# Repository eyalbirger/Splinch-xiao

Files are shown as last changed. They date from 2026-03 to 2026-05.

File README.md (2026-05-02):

# Splinch xiao
this is a 60 keys split ortho col staggered wireless keyboard that uses the 
xiao nrf52840 as its micro controller and zmk as firmwere.

i decided to build this because my current 60% razer gaming keeb, which has really bad software, hurts my wrist, ugly and sounds really annoying.
i got the idea to build this when i saw the ferris sweep on youtube and it looked supppppper cool.

BOM:
| name | quantity | value | lcsc # | price | source | pic |
|:----:|:---:|:-----:|:---:|:-----:|:---:|:---:|
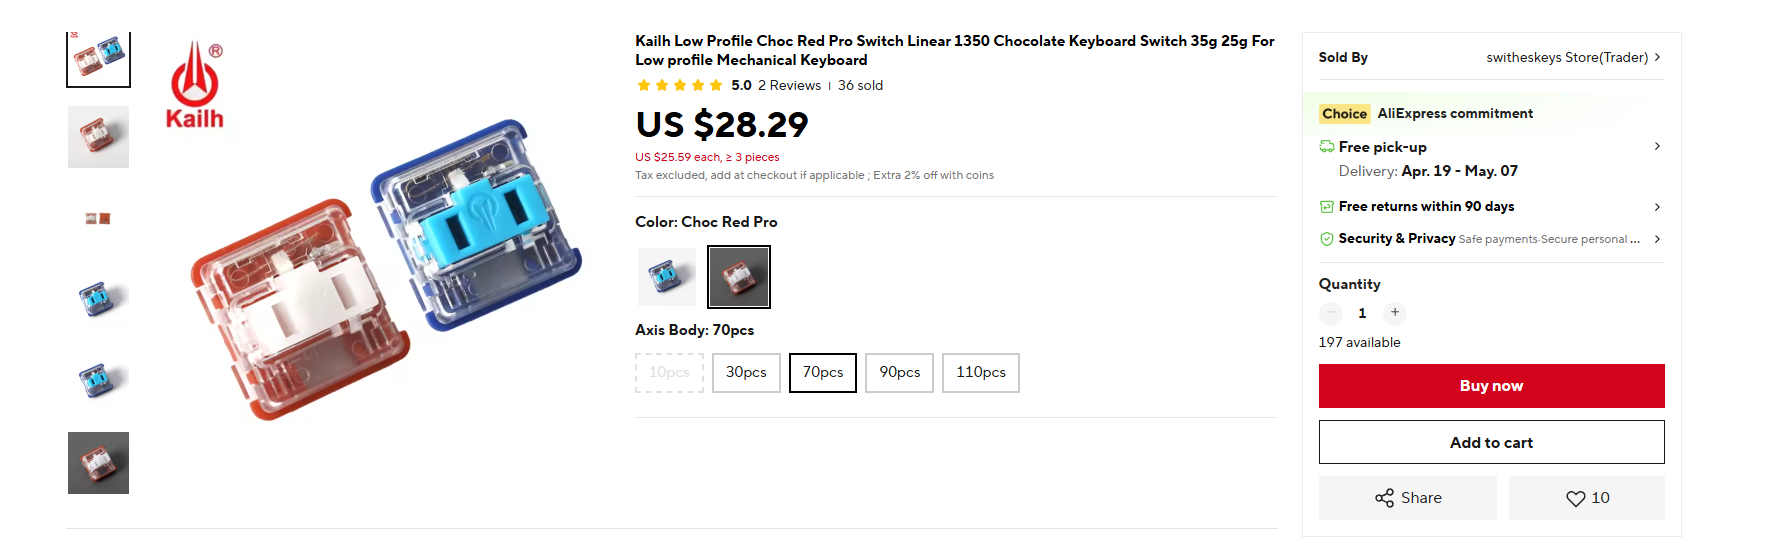
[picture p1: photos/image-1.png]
| choc switches | 62 | - | - | 30$ | https://he.aliexpress.com/item/1005010420712566.html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 |  |
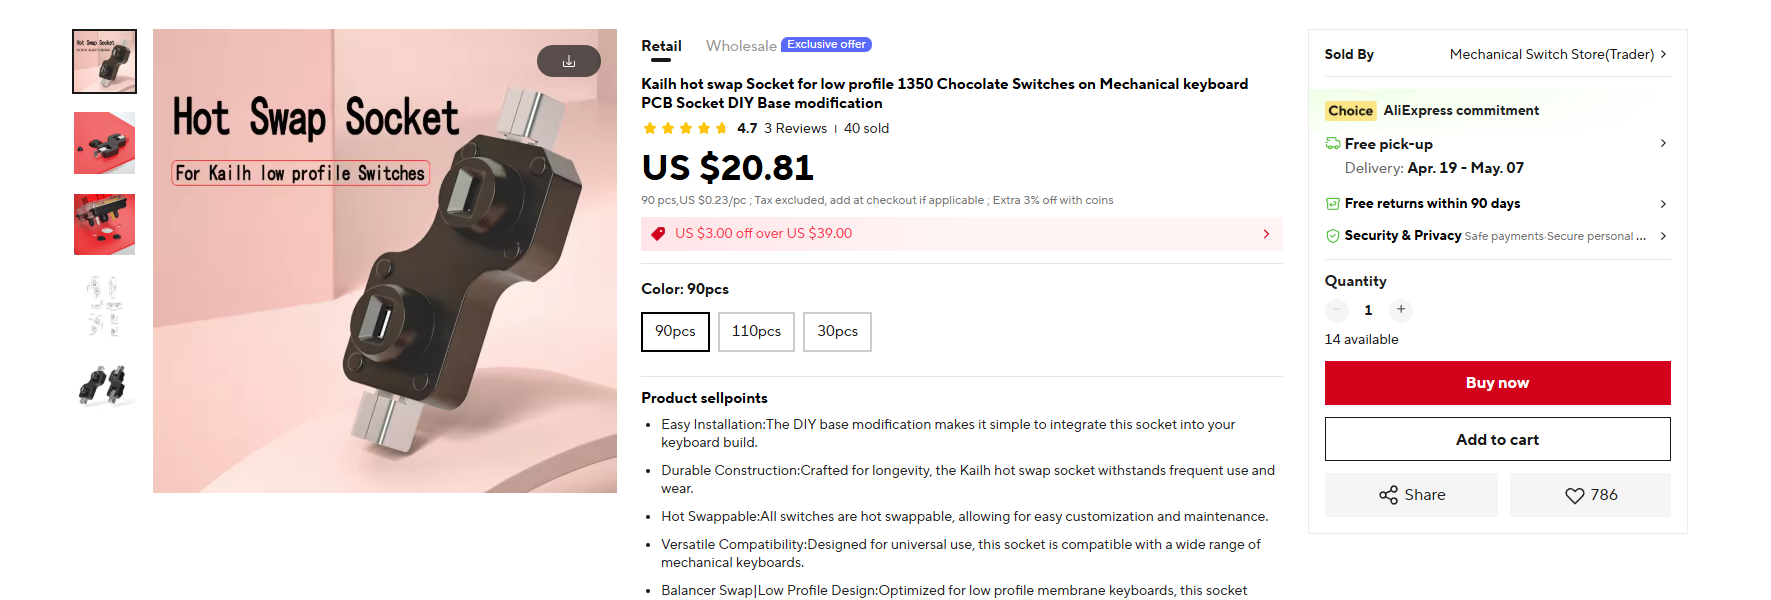
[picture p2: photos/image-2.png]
| choc hot swap socket | 62 | - | - | 20$ | https://he.aliexpress.com/item/33023283633.html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 |  |
| diodes | 62 | 1N4148W (SOD-123) | C2128 |
| resistor | 2 | 0805, 2M | C106170 | 
| resistor | 2 | 0805, 806k | C63494 |
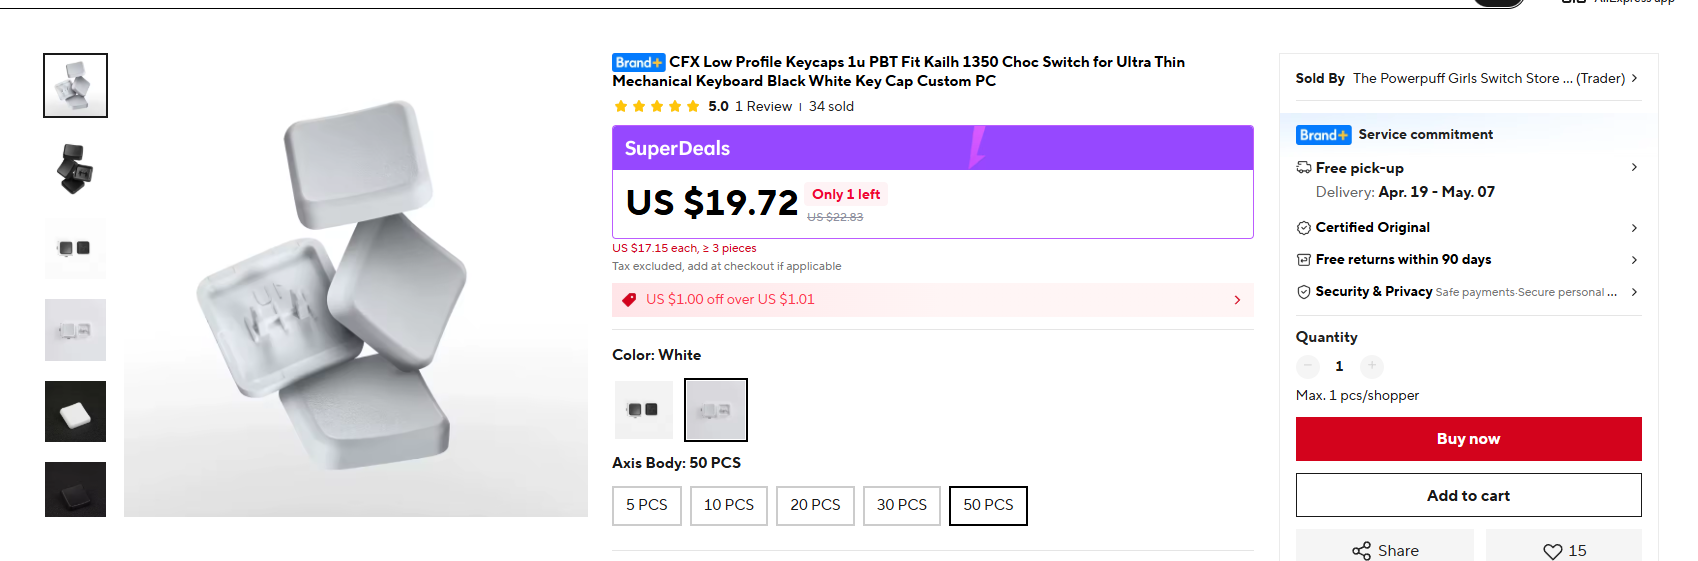
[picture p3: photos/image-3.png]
| keycaps | 62 | - | - | 27$ | https://he.aliexpress.com/item/1005010385514024.html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 |  |
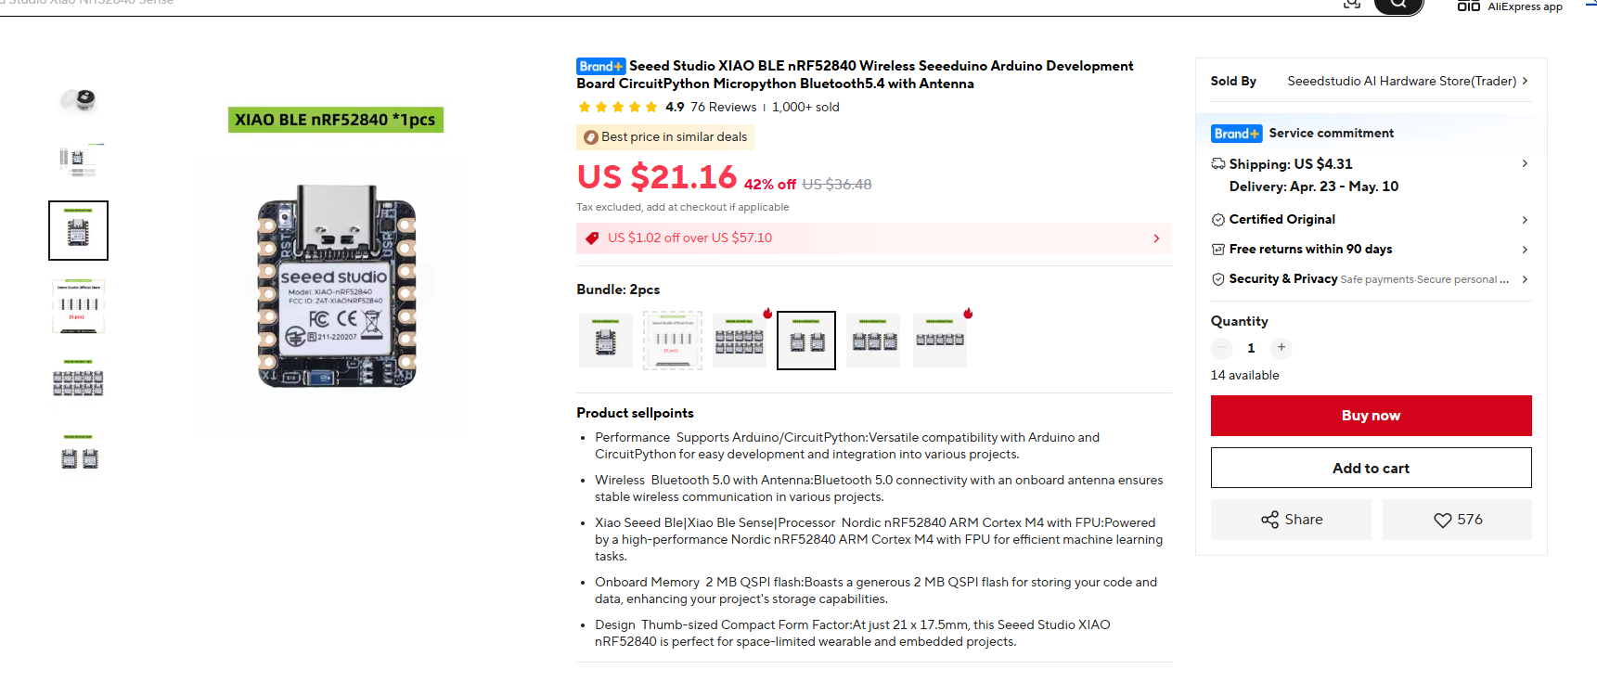
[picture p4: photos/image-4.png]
| nrf52 xiao | 2 | - | - | 40$ | https://he.aliexpress.com/item/1005006988954136.html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 |  |
| switch | 2 | MSK12C02 | - |
| screws | 8 | m2 | - |
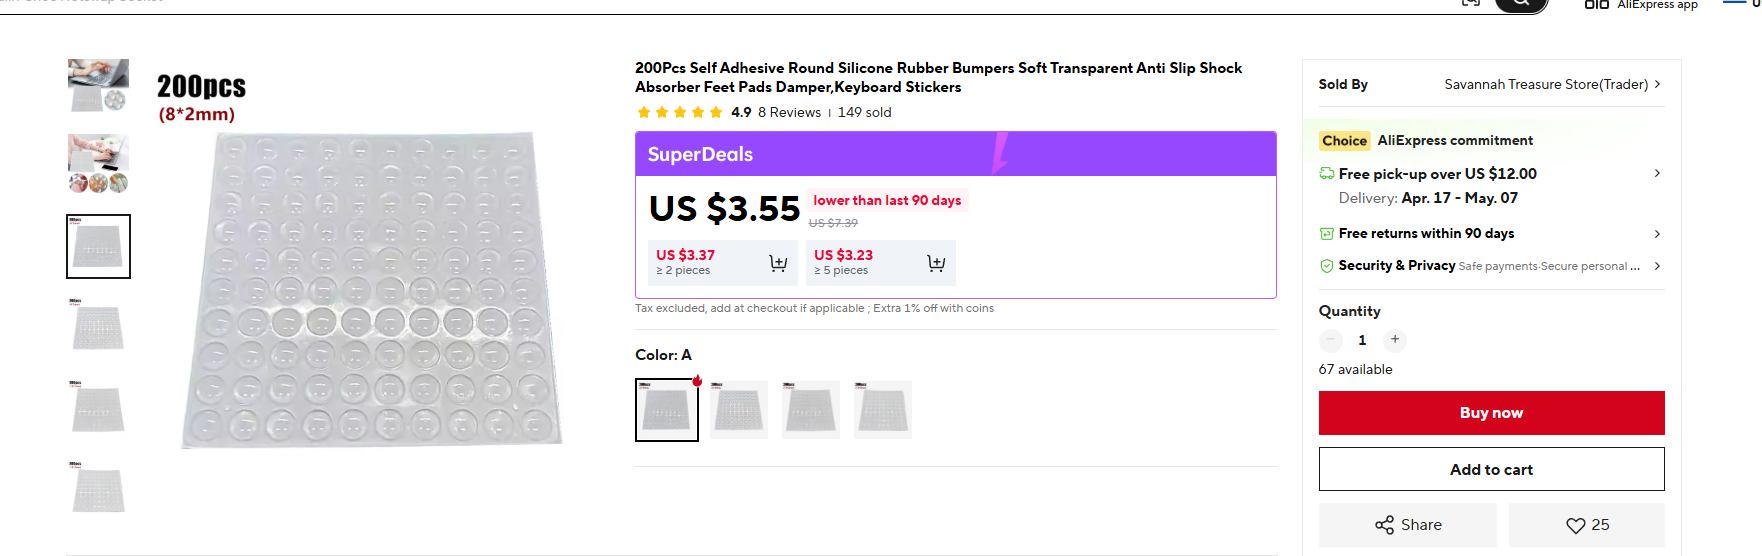
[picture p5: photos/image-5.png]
| silicone feet | some | - | - | 7$ | https://he.aliexpress.com/item/1005010241201821.html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 |  |
| nice nano | 1 | - | - | - | - | - |
| TOTAL | - | - | - | 124$ | - | - |

in order to complete that you also need the pcb. you can choose to use the pcba or assamble it yourself. i reccomend to use the pcba with the ressistors and the doides, and hand soldering the others.
this is the pcb:
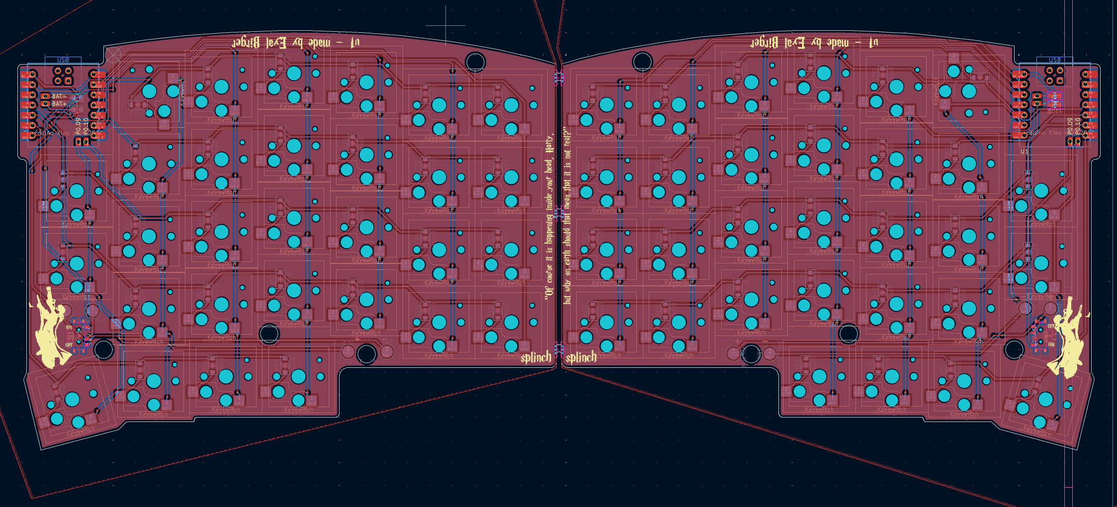
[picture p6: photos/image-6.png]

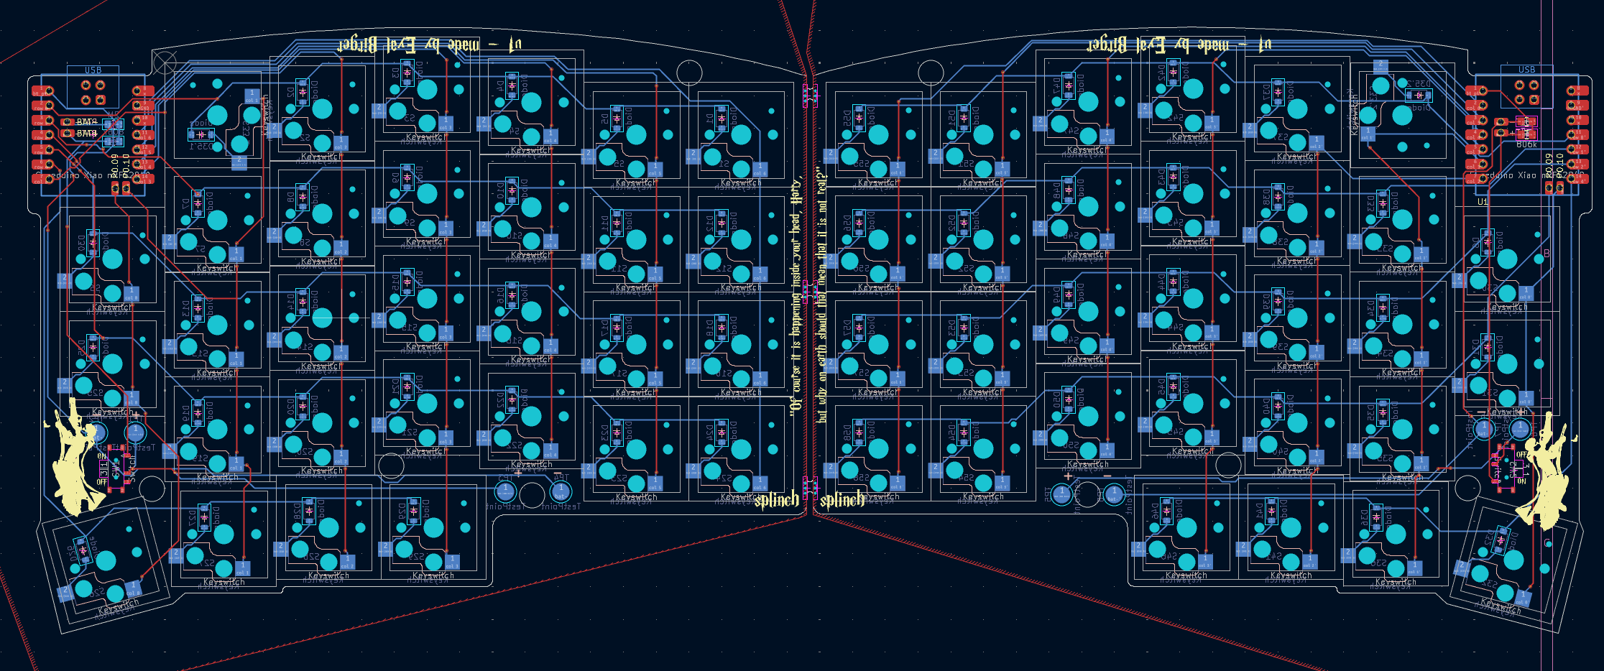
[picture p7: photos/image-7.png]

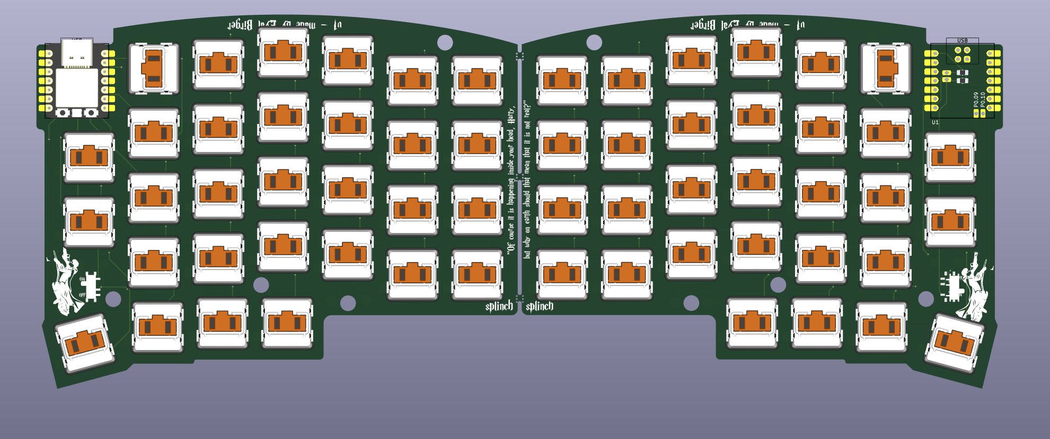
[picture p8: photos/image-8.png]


this is the case:
you need **8 m2 standoffs**, you can glue them with superglue into the standoff holes.
you also need **8 m2 screws** to screw the pcb to the case.
you can put a **6mm (max) thick battery**.
you need to mirror the case for the left part.
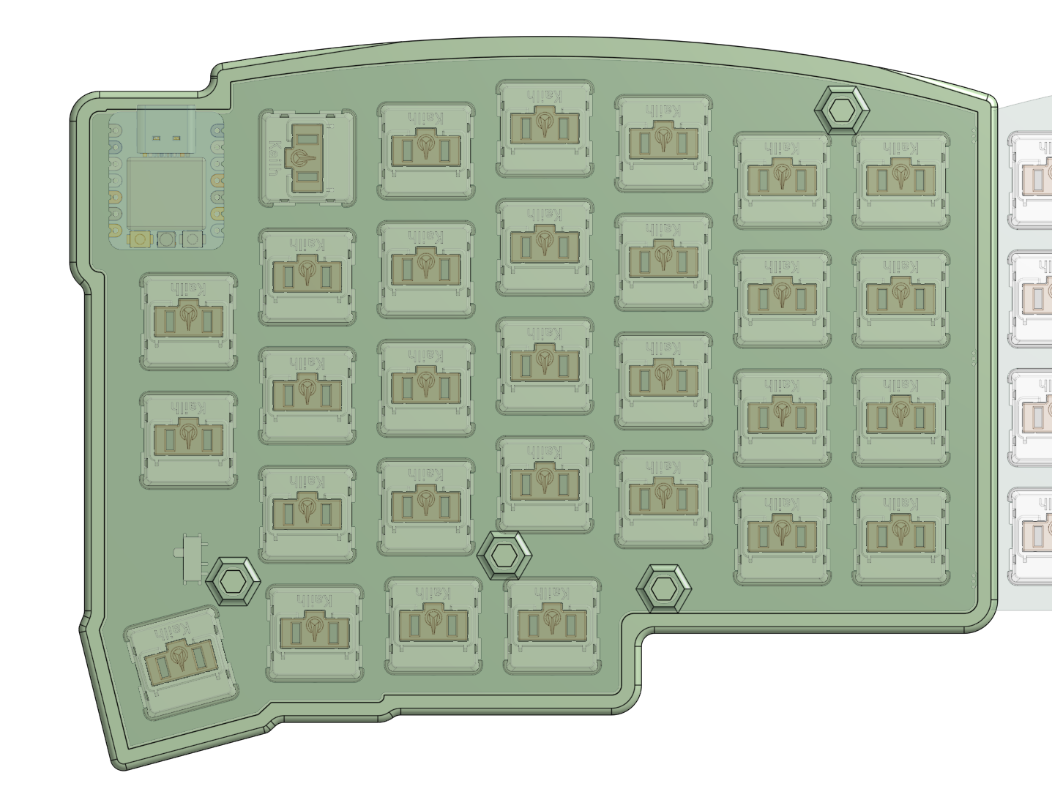
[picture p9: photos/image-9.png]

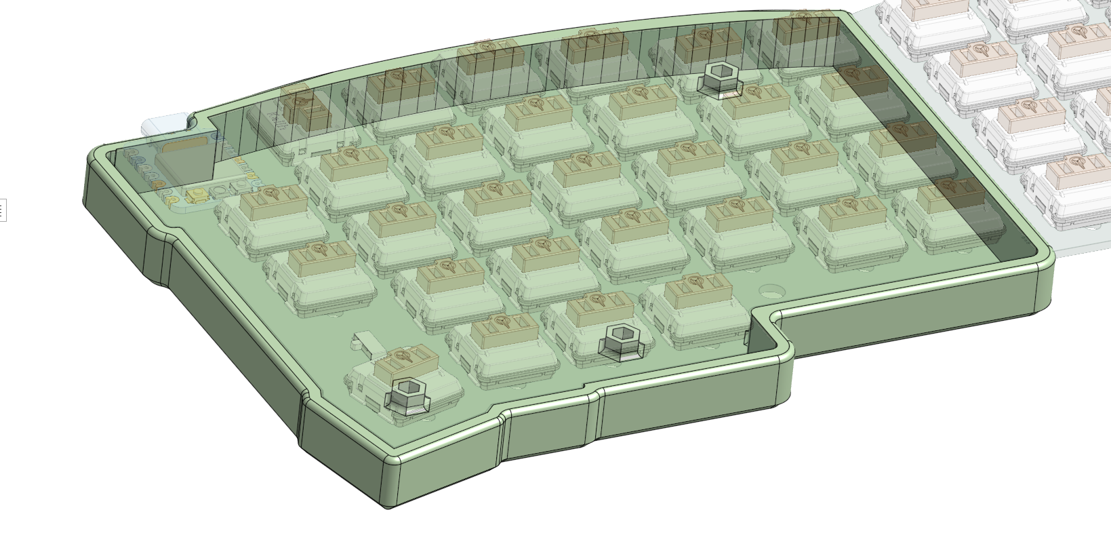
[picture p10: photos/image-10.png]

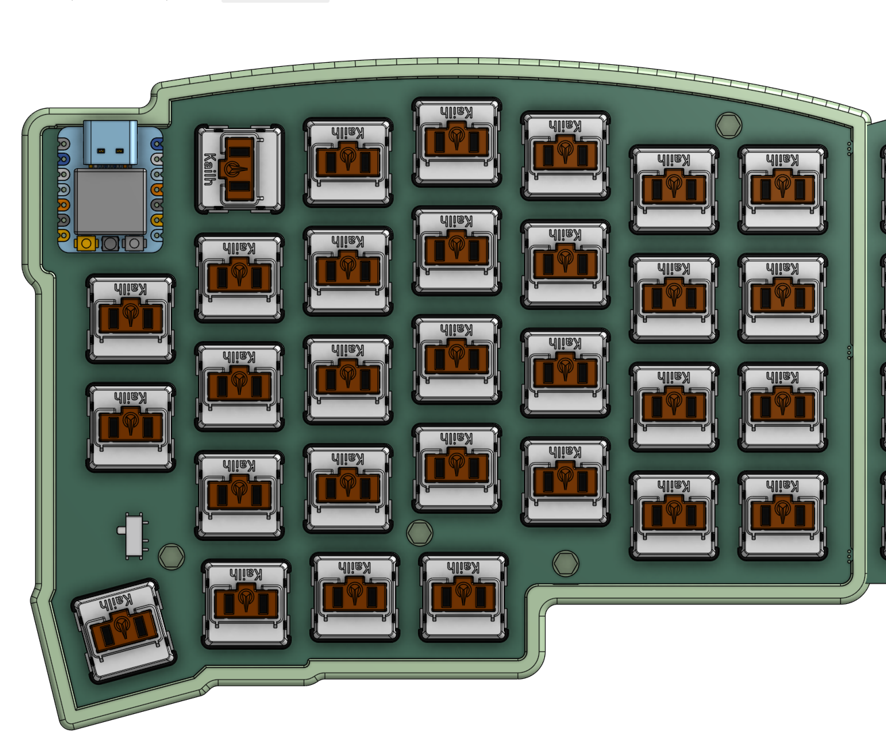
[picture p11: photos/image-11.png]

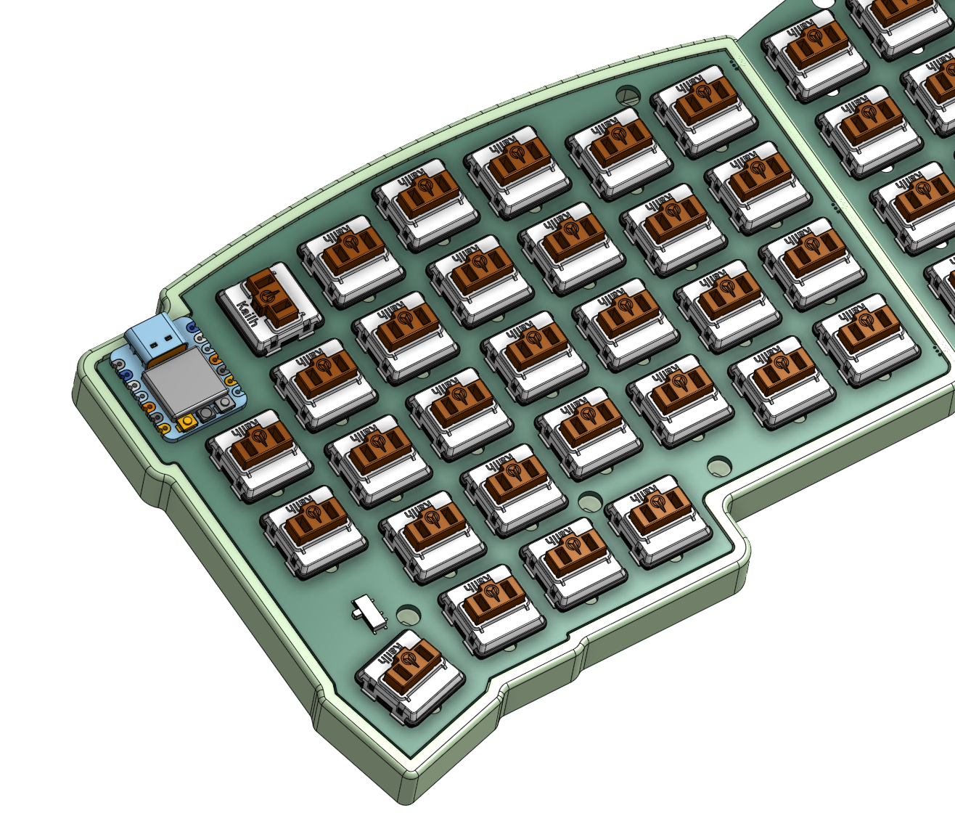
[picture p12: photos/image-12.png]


firmware: https://github.com/eyalbirger/zmk-config-splinch.git
i still need to complete and test the firmware (i have like one build error), but it will probably be completed in a few days (i have a war to deal with, so you know...).

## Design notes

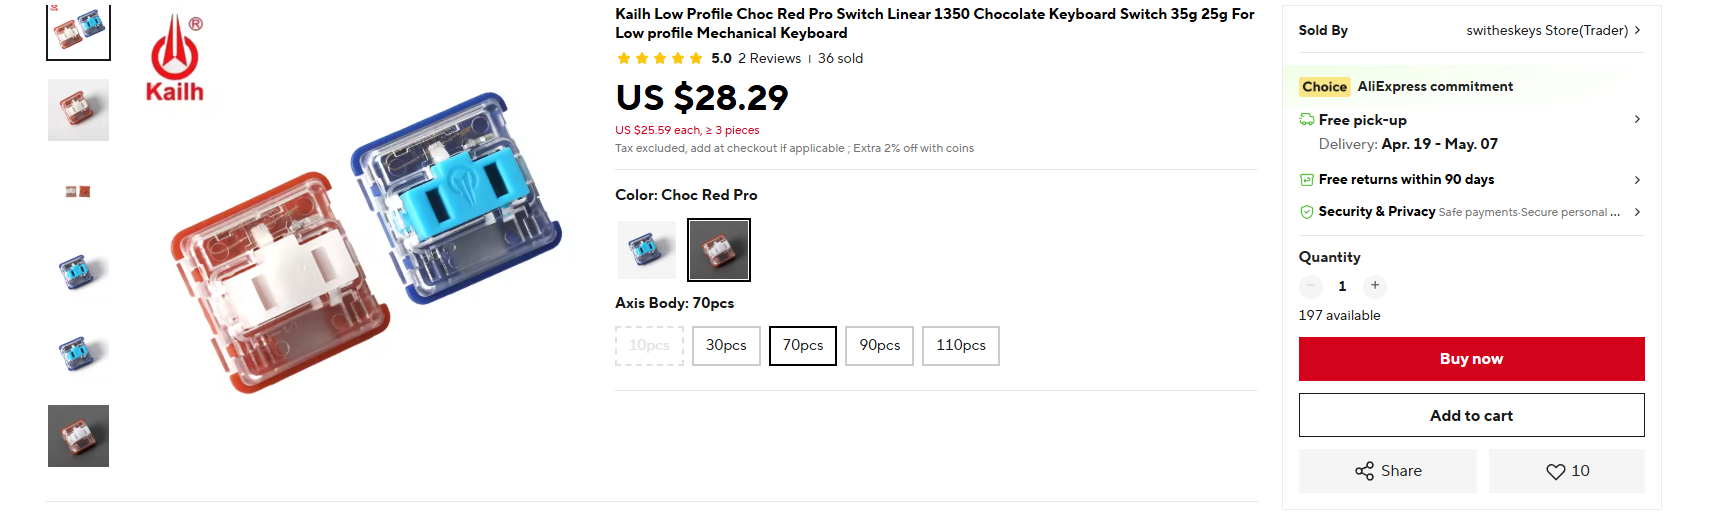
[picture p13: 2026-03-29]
photos/image.png

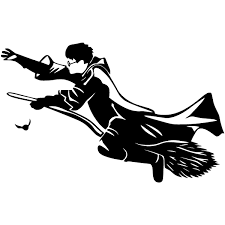
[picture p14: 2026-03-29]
Splinch xiao/photos/images.png

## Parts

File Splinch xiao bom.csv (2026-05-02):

Name | Quantity | Value | LCSC # | Price | Source
Choc switches | 58 | - | - | 30$ | https://he.aliexpress.com/item/1005010420712566.html
Choc hot swap socket | 58 | - | - | 20$ | https://he.aliexpress.com/item/33023283633.html
Diodes | 58 | 1N4148W (SOD-123) | C2128
Resistor | 2 | 0805 2M | C106170
Resistor | 2 | 0805 806k | C63494
Keycaps | 58 | - | - | 27$ | https://he.aliexpress.com/item/1005010385514024.html
NRF52 XIAO | 2 | - | - | 40$ | https://he.aliexpress.com/item/1005006988954136.html
Switch | 2 | MSK12C02 | -
Screws | 8 | M2 | -
Silicone feet | some | - | - | 7$ | https://he.aliexpress.com/item/1005010241201821.html
Nice Nano | 1 | - | -
TOTAL |  |  |  | 124$

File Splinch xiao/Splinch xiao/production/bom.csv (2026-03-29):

Designator | Footprint | Quantity | Value | LCSC Part #
D1, D10, D11, D12, D13, D14, D15, D16, D17, D18, D19, D2, D20, D21, D22, D23, D24, D25, D26, D27, D28, D29, D3, D30, D31, D32, D33, D34, D35, D35'1, D35'2, D36, D37, D38, D39, D4, D40, D41, D42, D43, D44, D45, D46, D47, D48, D49, D5, D50, D51, D52, D53, D54, D55, D56, D57, D58, D6, D7, D8, D9 | Diode_SOD-123 | 60 | Diode
R1, R3 | 0805 | 2 | 806k
R2, R4 | 0805 | 2 | 2M
S1, S10, S11, S12, S13, S14, S15, S16, S17, S18, S19, S2, S20, S21, S22, S23, S24, S25, S26, S27, S28, S29, S3, S30, S31, S32, S33, S33'1, S33'2, S34, S35, S36, S37, S38, S39, S4, S40, S41, S42, S43, S44, S45, S46, S47, S48, S49, S5, S50, S51, S52, S53, S54, S55, S56, S57, S58, S6, S7, S8, S9 | Kailh_socket_PG1350 | 60 | Keyswitch
SW1, SW2 | Switch_MSK12C02 | 2 | Switch
TP1, TP2, TP3, TP4, TP5, TP6, TP7, TP8 | TestPoint_Pad_D3.0mm | 8 | TestPoint

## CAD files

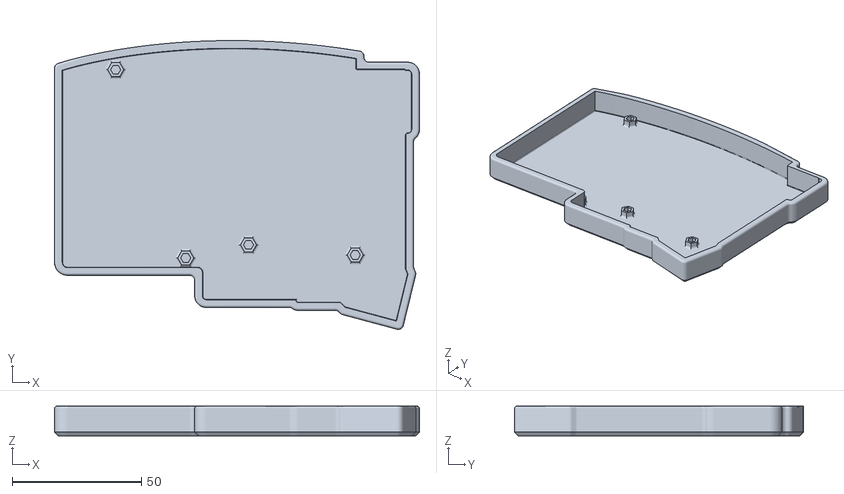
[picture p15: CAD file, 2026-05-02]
CAD/case left.stl
141.4 x 111.9 x 11.6

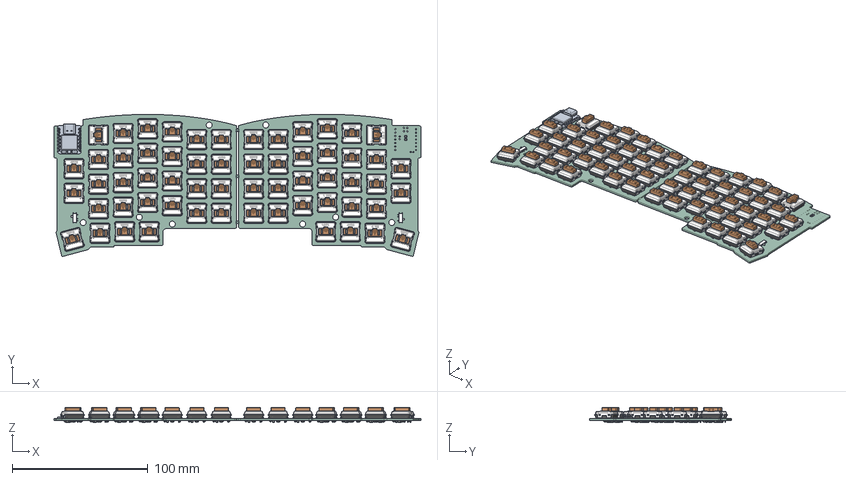
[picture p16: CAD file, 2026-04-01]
Splinch xiao/Splinch xiao/for cad/Splinch xiao.step
270.4 x 104.8 x 11.0 mm
Choc_V1 x 58
Splinch xiao 1.17.1
Switch_MSK12C02 x 2
R_0805_2012Metric x 4
Diode_SOD-123 x 58
Splinch xiao_PCB

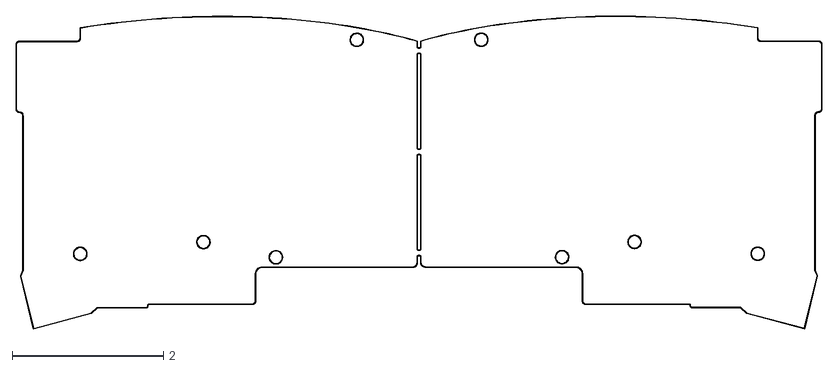
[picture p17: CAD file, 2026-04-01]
Splinch xiao/Splinch xiao/Splinch xiao-Edge_Cuts.dxf
10.6 x 4.13

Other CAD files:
CAD/case right stl.stl
CAD/case right step.step

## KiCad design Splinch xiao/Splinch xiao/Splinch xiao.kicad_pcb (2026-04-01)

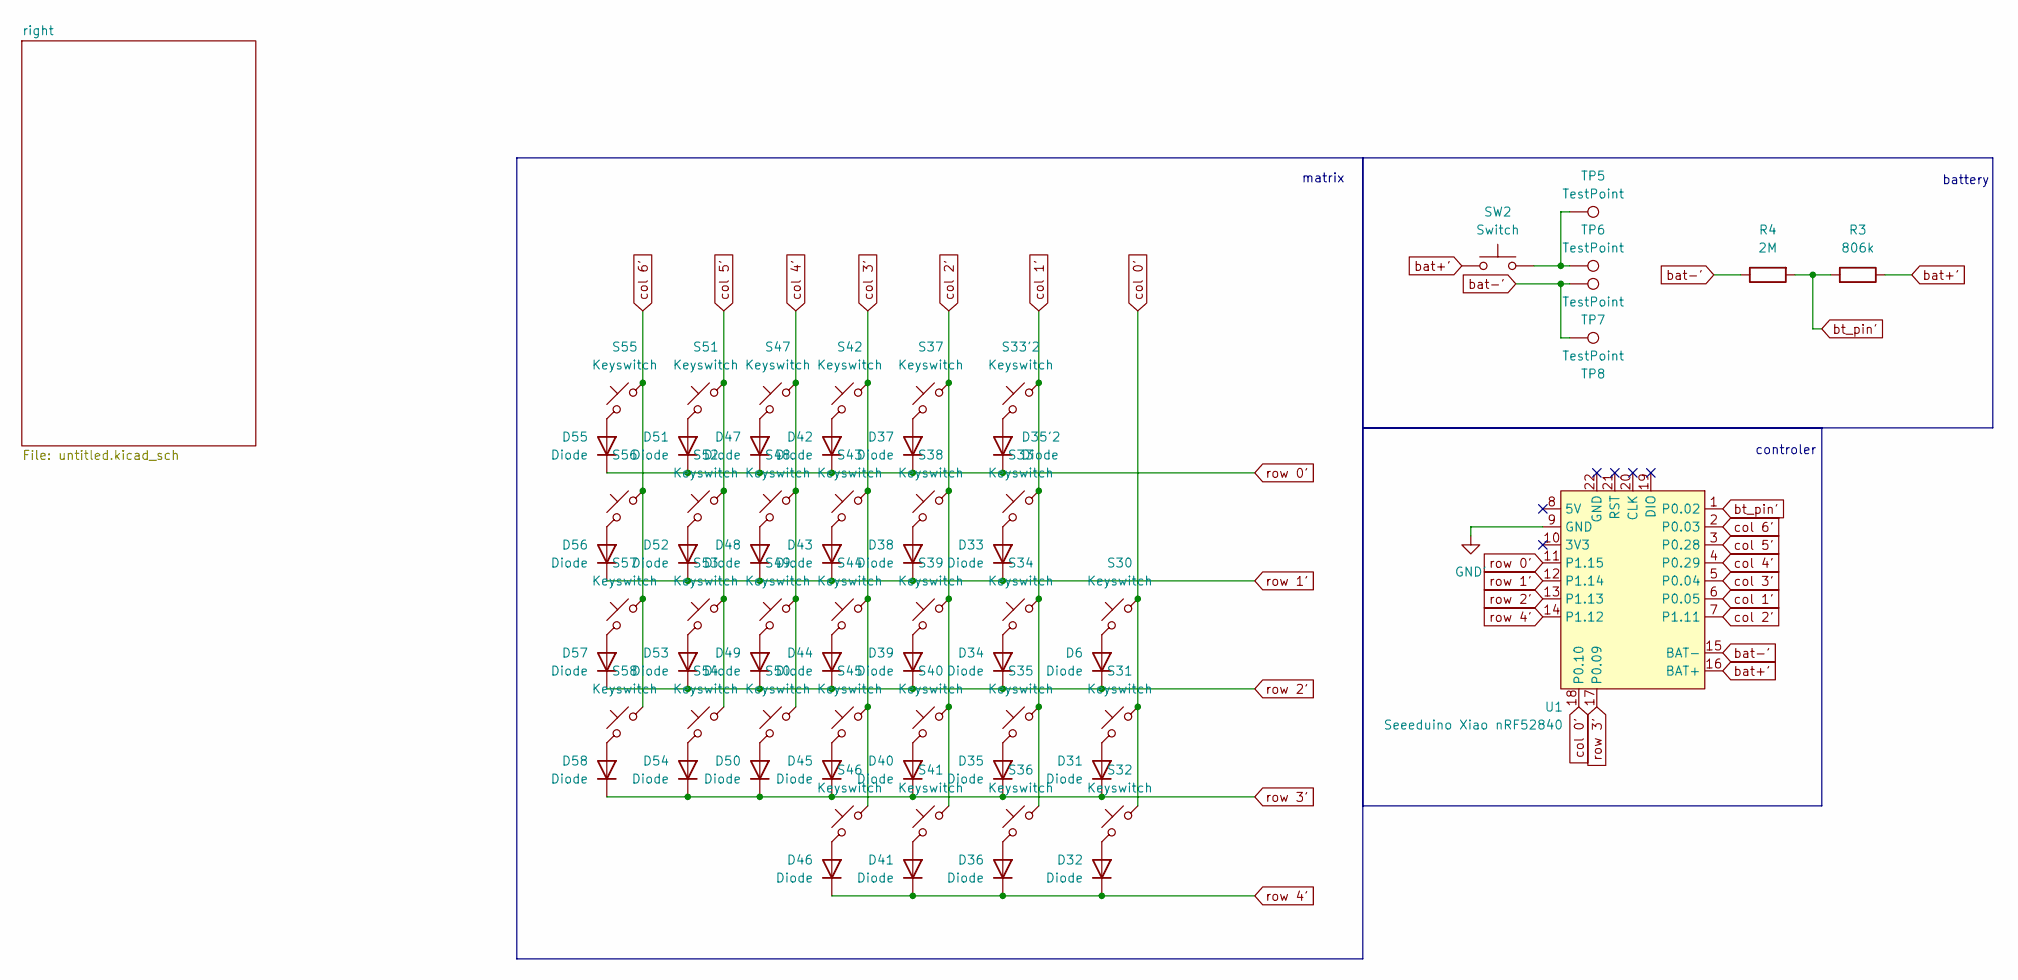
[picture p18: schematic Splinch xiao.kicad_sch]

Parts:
D6, D31, D32, D33, D34, D35, D35'2, D36, D37, D38, D39, D40, D41, D42, D43, D44, D45, D46, D47, D48, D49, D50, D51, D52, D53, D54, D55, D56, D57, D58: Diode; Diode_SOD-123; LCSC C2128
R3: 806k; R_0805_2012Metric_Pad1.20x1.40mm_HandSolder; LCSC C121025
R4: 2M; R_0805_2012Metric_Pad1.20x1.40mm_HandSolder; LCSC C106170
S30, S31, S32, S33, S33'2, S34, S35, S36, S37, S38, S39, S40, S41, S42, S43, S44, S45, S46, S47, S48, S49, S50, S51, S52, S53, S54, S55, S56, S57, S58: Keyswitch; Kailh_socket_PG1350
SW2: Switch; Switch_MSK12C02
TP5, TP6, TP7, TP8: TestPoint; TestPoint_Pad_D3.0mm
U1: Seeeduino Xiao nRF52840; Xiao_nRF52840_ACH

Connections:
GND': U1.9 (GND)
unnamed: D6.2 (A), S30.2
unnamed: D31.2 (A), S31.2
unnamed: D32.2 (A), S32.2
unnamed: D33.2 (A), S33.2
unnamed: D34.2 (A), S34.2
unnamed: D35'2.2 (A), S33'2.2
unnamed: D35.2 (A), S35.2
unnamed: D36.2 (A), S36.2
unnamed: D37.2 (A), S37.2
unnamed: D38.2 (A), S38.2
unnamed: D39.2 (A), S39.2
unnamed: D40.2 (A), S40.2
unnamed: D41.2 (A), S41.2
unnamed: D42.2 (A), S42.2
unnamed: D43.2 (A), S43.2
unnamed: D44.2 (A), S44.2
unnamed: D45.2 (A), S45.2
unnamed: D46.2 (A), S46.2
unnamed: D47.2 (A), S47.2
unnamed: D48.2 (A), S48.2
unnamed: D49.2 (A), S49.2
unnamed: D50.2 (A), S50.2
unnamed: D51.2 (A), S51.2
unnamed: D52.2 (A), S52.2
unnamed: D53.2 (A), S53.2
unnamed: D54.2 (A), S54.2
unnamed: D55.2 (A), S55.2
unnamed: D56.2 (A), S56.2
unnamed: D57.2 (A), S57.2
unnamed: D58.2 (A), S58.2
unnamed: SW2.2, TP5.1, TP6.1
bat+': R3.1, SW2.1, U1.16 (BAT+)
bat-': R4.1, TP7.1, TP8.1, U1.15 (BAT-)
bt_pin': R3.2, R4.2, U1.1 (P0.02)
col 0': S30.1, S31.1, S32.1, U1.18 (P0.10)
col 1': S33.1, S33'2.1, S34.1, S35.1, S36.1, U1.6 (P0.05)
col 2': S37.1, S38.1, S39.1, S40.1, S41.1, U1.7 (P1.11)
col 3': S42.1, S43.1, S44.1, S45.1, S46.1, U1.5 (P0.04)
col 4': S47.1, S48.1, S49.1, S50.1, U1.4 (P0.29)
col 5': S51.1, S52.1, S53.1, S54.1, U1.3 (P0.28)
col 6': S55.1, S56.1, S57.1, S58.1, U1.2 (P0.03)
row 0': D35'2.1 (K), D37.1 (K), D42.1 (K), D47.1 (K), D51.1 (K), D55.1 (K), U1.11 (P1.15)
row 1': D33.1 (K), D38.1 (K), D43.1 (K), D48.1 (K), D52.1 (K), D56.1 (K), U1.12 (P1.14)
row 2': D6.1 (K), D34.1 (K), D39.1 (K), D44.1 (K), D49.1 (K), D53.1 (K), D57.1 (K), U1.13 (P1.13)
row 3': D31.1 (K), D35.1 (K), D40.1 (K), D45.1 (K), D50.1 (K), D54.1 (K), D58.1 (K), U1.17 (P0.09)
row 4': D32.1 (K), D36.1 (K), D41.1 (K), D46.1 (K), U1.14 (P1.12)

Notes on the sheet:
controler
battery
matrix

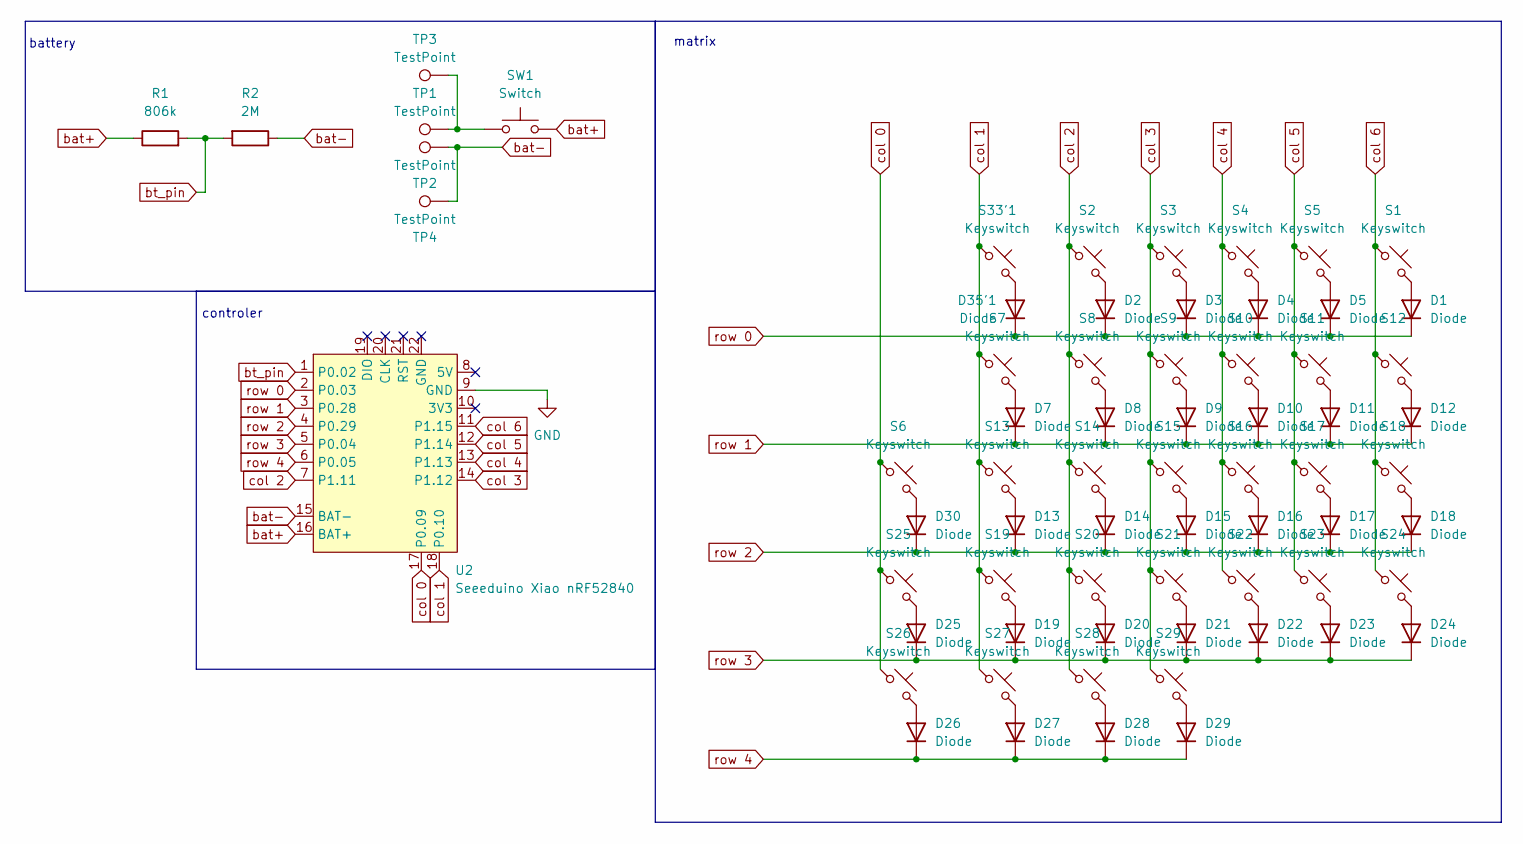
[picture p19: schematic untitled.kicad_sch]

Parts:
D1, D2, D3, D4, D5, D7, D8, D9, D10, D11, D12, D13, D14, D15, D16, D17, D18, D19, D20, D21, D22, D23, D24, D25, D26, D27, D28, D29, D30, D35'1: Diode; Diode_SOD-123; LCSC C2128
R1: 806k; R_0805_2012Metric_Pad1.20x1.40mm_HandSolder; LCSC C121025
R2: 2M; R_0805_2012Metric_Pad1.20x1.40mm_HandSolder; LCSC C106170
S1, S2, S3, S4, S5, S6, S7, S8, S9, S10, S11, S12, S13, S14, S15, S16, S17, S18, S19, S20, S21, S22, S23, S24, S25, S26, S27, S28, S29, S33'1: Keyswitch; Kailh_socket_PG1350
SW1: Switch; Switch_MSK12C02
TP1, TP2, TP3, TP4: TestPoint; TestPoint_Pad_D3.0mm
U2: Seeeduino Xiao nRF52840; Xiao_nRF52840_ACH

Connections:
GND: U2.9 (GND)
unnamed: D1.2 (A), S1.2
unnamed: D2.2 (A), S2.2
unnamed: D3.2 (A), S3.2
unnamed: D4.2 (A), S4.2
unnamed: D5.2 (A), S5.2
unnamed: D7.2 (A), S7.2
unnamed: D8.2 (A), S8.2
unnamed: D9.2 (A), S9.2
unnamed: D10.2 (A), S10.2
unnamed: D11.2 (A), S11.2
unnamed: D12.2 (A), S12.2
unnamed: D13.2 (A), S13.2
unnamed: D14.2 (A), S14.2
unnamed: D15.2 (A), S15.2
unnamed: D16.2 (A), S16.2
unnamed: D17.2 (A), S17.2
unnamed: D18.2 (A), S18.2
unnamed: D19.2 (A), S19.2
unnamed: D20.2 (A), S20.2
unnamed: D21.2 (A), S21.2
unnamed: D22.2 (A), S22.2
unnamed: D23.2 (A), S23.2
unnamed: D24.2 (A), S24.2
unnamed: D25.2 (A), S25.2
unnamed: D26.2 (A), S26.2
unnamed: D27.2 (A), S27.2
unnamed: D28.2 (A), S28.2
unnamed: D29.2 (A), S29.2
unnamed: D30.2 (A), S6.2
unnamed: D35'1.2 (A), S33'1.2
unnamed: SW1.2, TP1.1, TP3.1
bat+: R1.1, SW1.1, U2.16 (BAT+)
bat-: R2.1, TP2.1, TP4.1, U2.15 (BAT-)
bt_pin: R1.2, R2.2, U2.1 (P0.02)
col 0: S6.1, S25.1, S26.1, U2.17 (P0.09)
col 1: S7.1, S13.1, S19.1, S27.1, S33'1.1, U2.18 (P0.10)
col 2: S2.1, S8.1, S14.1, S20.1, S28.1, U2.7 (P1.11)
col 3: S3.1, S9.1, S15.1, S21.1, S29.1, U2.14 (P1.12)
col 4: S4.1, S10.1, S16.1, S22.1, U2.13 (P1.13)
col 5: S5.1, S11.1, S17.1, S23.1, U2.12 (P1.14)
col 6: S1.1, S12.1, S18.1, S24.1, U2.11 (P1.15)
row 0: D1.1 (K), D2.1 (K), D3.1 (K), D4.1 (K), D5.1 (K), D35'1.1 (K), U2.2 (P0.03)
row 1: D7.1 (K), D8.1 (K), D9.1 (K), D10.1 (K), D11.1 (K), D12.1 (K), U2.3 (P0.28)
row 2: D13.1 (K), D14.1 (K), D15.1 (K), D16.1 (K), D17.1 (K), D18.1 (K), D30.1 (K), U2.4 (P0.29)
row 3: D19.1 (K), D20.1 (K), D21.1 (K), D22.1 (K), D23.1 (K), D24.1 (K), D25.1 (K), U2.5 (P0.04)
row 4: D26.1 (K), D27.1 (K), D28.1 (K), D29.1 (K), U2.6 (P0.05)

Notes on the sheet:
matrix
controler
battery

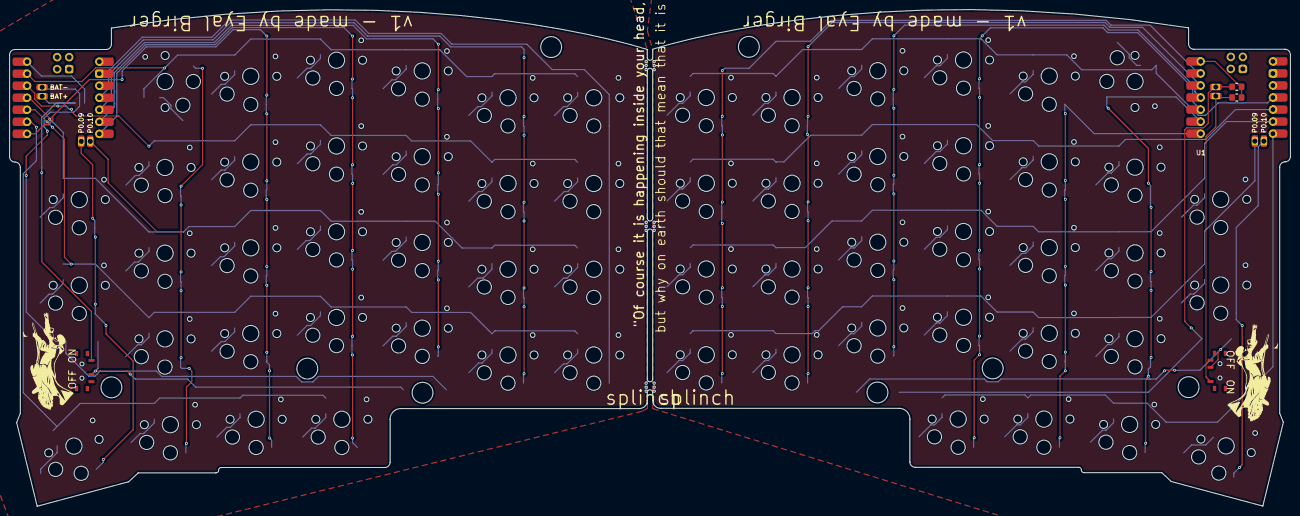
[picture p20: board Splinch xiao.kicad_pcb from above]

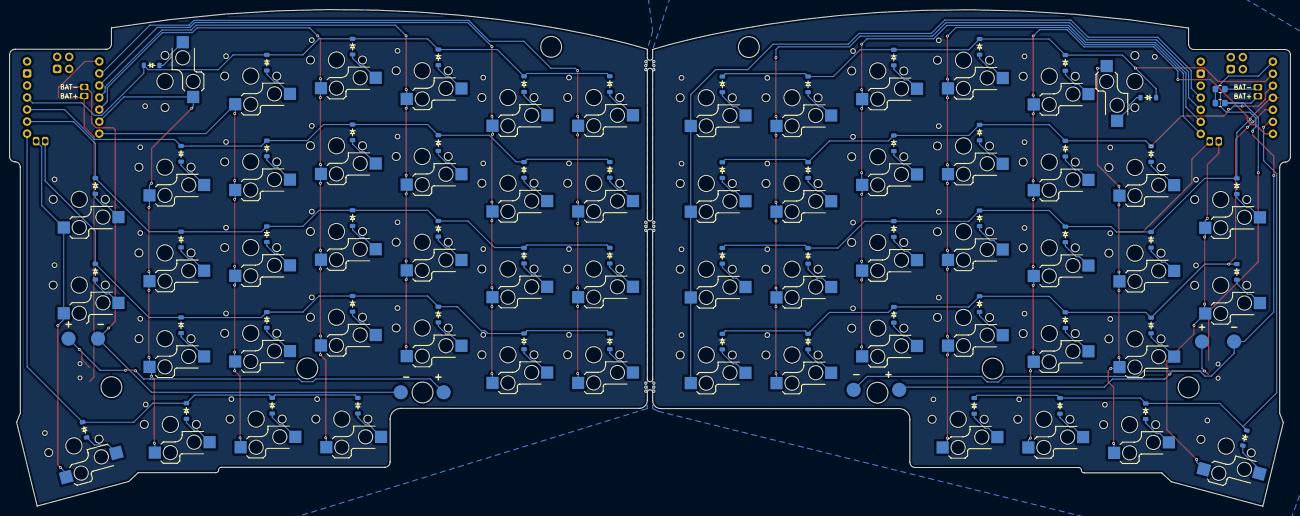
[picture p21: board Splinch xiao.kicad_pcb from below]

Board: 2 copper layers, 270.4 x 104.8 mm, 136 parts (70 on the bottom side), 92 nets.

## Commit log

2026-01-18 schem + pcb
    [Splinch xiao.kicad_pcb, Splinch xiao.kicad_sch, untitled.kicad_sch]
2026-01-26 outline and left schem
    [Splinch xiao.kicad_pcb, Splinch xiao.kicad_sch]
2026-01-26 did some of the other galf
    [Splinch xiao.kicad_pcb, Splinch xiao.kicad_sch]
2026-03-29 case' wiring and more
    [Splinch xiao.kicad_pcb, Splinch xiao.kicad_sch, untitled.kicad_sch]
2026-03-29 added silk screen and reade me
    [Splinch xiao.kicad_pcb, Splinch xiao.kicad_sch, bom.csv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]
2026-03-29 garber for the new pcb
    [designators.csv]
2026-04-01 readme, cad
    [Splinch xiao-Edge_Cuts.dxf, Splinch xiao.kicad_pcb, Splinch xiao.step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]
2026-05-02 case left and readme
    [Splinch xiao bom.csv, case left.stl]
